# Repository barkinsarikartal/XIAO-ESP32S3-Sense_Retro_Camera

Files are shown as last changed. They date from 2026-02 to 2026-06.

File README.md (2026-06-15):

# XIAO ESP32-S3 Sense Retro Camera

A compact retro-styled digital camera built on the Seeed Studio XIAO ESP32-S3 Sense. Captures high-resolution photos and MJPEG/PCM audio video, with a live viewfinder on a 2.0" TFT display. Features a full encoder-driven menu system with on-device gallery (including video thumbnail previews), camera settings, self-timer countdown, timelapse mode, photo slideshow, and a tabbed wireless file manager. Modular codebase with a multi-task FreeRTOS architecture for robust, concurrent operation.

---

## Demo Video

<div align="center">
  <a href="https://youtu.be/0UTXGptOVkc">
    XIAO ESP32-S3 Retro Camera — Demo Video
  </a>
  <br>
  <strong><a href="https://youtu.be/0UTXGptOVkc">Watch the full demo on YouTube</a></strong>
</div>

---

## Features

- **High-Resolution Photo Capture** — HD JPEG images (1280×720) saved to SD card
- **Video Recording with Audio** — MJPEG video at 480×320, 10 FPS, with 16 kHz mono PCM audio via the built-in PDM microphone, saved as `.avi`
- **Live Viewfinder** — Real-time 320×240 RGB565 camera preview on the TFT display
- **Main Menu** — Encoder-driven main menu with Gallery, WiFi Transfer, Camera Settings, Timelapse, Slideshow, and Exit options
- **Camera Settings** — On-device configuration of 15 parameters (brightness, contrast, saturation, AE level, white balance, special effects, mirror, flip, JPEG quality, timelapse interval, recording duration limit, flashlight toggle, file counter reset, self-timer, slideshow interval) with NVS persistence
- **Self-Timer** — Configurable countdown (3 / 5 / 10 s) before photo capture; large digit on TFT; LED blinks slowly then rapidly in the last second; cancel anytime with the shutter button
- **Timelapse Mode** — Periodic HD photo capture at configurable intervals (5s–10min); TFT shows countdown, photo count, elapsed time; pause/resume/stop via encoder
- **Slideshow Mode** — Auto-advance full-screen photo slideshow from the main menu; configurable interval (3 / 5 / 10 s); pause/resume (encoder click), exit (encoder long press), emergency exit (shutter)
- **Recording Duration Limit** — Configurable auto-stop for video recording (30s–15min or unlimited)
- **LED Flashlight & Recording Indicator** — General-purpose LED flashlight that also acts as a 1 Hz blinking recording indicator or continuous video light; also blinks as self-timer cue
- **FPS Counter & SD Status** — Live overlay showing frame rate and SD card health
- **WiFi File Server** — AP mode with a tabbed HTML file manager (Photos / Videos tabs with file count badges, sorted newest-first); download with browser progress bar, preview, delete individual files, **bulk-select and delete multiple files**, or **delete all** photos/videos in one tap; video thumbnail support; **QR code pairing screen** on the TFT displays credentials and a scannable WIFI: QR code for instant phone connection
- **On-Device Gallery** — Browse photos and videos in a **4×3 thumbnail grid** (12 items per page); drill into a full-screen detail view with encoder click; video thumbnails show a play icon overlay; page indicator shows current position
- **Silent Video Playback** — Plays AVI recordings on the TFT by parsing MOVI JPEG chunks; frame timing derived from the AVI header's `microSecPerFrame` for accurate real-time speed; pause/resume/stop via encoder
- **File Deletion** — Delete photos and videos directly from the device with a confirmation dialog
- **Reliable AVI Encoding** — Accurate `idx1` index table built from actual chunk write order; `microSecPerFrame` derived from declared target FPS; `endAVI()` safely handles SD removal mid-recording
- **A/V Synchronisation** — I2S DMA geometry tuned to drain exactly one video frame's worth of audio per read (`AUDIO_BYTES_PER_FRAME = 3200` bytes, 10×320-byte DMA slots); fixes cumulative drift
- **Atomic Multi-Core Synchronisation** — `std::atomic<int>` for all inter-core display-buffer state, preventing SMP data races
- **PSRAM Efficiency** — Separate `DISP_BUF_SIZE` (160 KB) and `REC_BUF_SIZE` (80 KB) buffer pools save 240 KB PSRAM; AVI metadata arrays allocated once at boot and `memset` per session

---

## Hardware

| Component | Part |
|---|---|
| Microcontroller | Seeed Studio XIAO ESP32-S3 Sense (OV2640 + SD card expansion) |
| Display | 2.0" TFT LCD — ST7789VW, 240×320, SPI |
| Rotary Encoder | EC11 with push button (CLK: GPIO 6, DT: GPIO 43, SW: GPIO 44) |
| Shutter button | 1× tactile button (GPIO 5 to GND) |
| LED Flashlights | 2× 5mm white LEDs with 100Ω resistor (GPIO 4) |
| Storage | MicroSD card, FAT32 formatted |
| Power | 3.7 V Li-ion battery or USB-C |

---

## Pin Configuration

<div align="center">
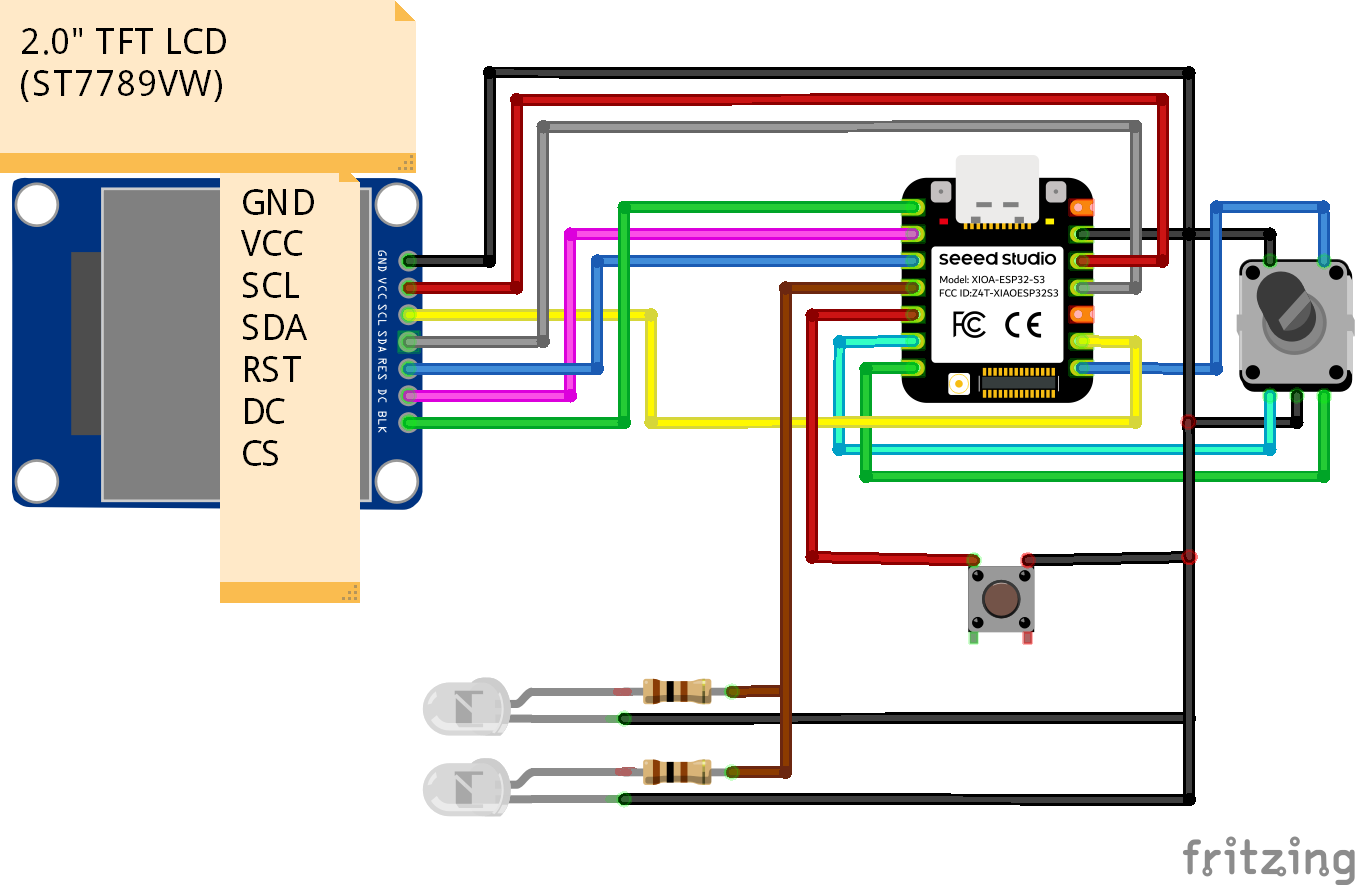
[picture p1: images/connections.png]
Connection Diagram
  
  <br><br>
  <table>
    <tr>
      <td valign="top" align="center">
        <h3>TFT Display (ST7789VW)</h3>
        <table>
          <tr><th>TFT Pin</th><th>GPIO</th></tr>
          <tr><td>GND</td><td>GND</td></tr>
          <tr><td>VCC</td><td>3.3 V</td></tr>
          <tr><td>SCL (SCK)</td><td>GPIO 7</td></tr>
          <tr><td>SDA (MOSI)</td><td>GPIO 9</td></tr>
          <tr><td>RESET</td><td>GPIO 3</td></tr>
          <tr><td>DC</td><td>GPIO 2</td></tr>
          <tr><td>CS</td><td>GPIO 1</td></tr>
        </table>
      </td>
      <td width="20"></td>
      <td valign="top" align="center">
        <h3>Buttons & Control</h3>
        <table>
          <tr><th>Function</th><th>GPIO</th></tr>
          <tr><td>Encoder CLK</td><td>GPIO 6 (INPUT_PULLUP)</td></tr>
          <tr><td>Encoder DT</td><td>GPIO 43 (INPUT_PULLUP)</td></tr>
          <tr><td>Encoder SW (Button)</td><td>GPIO 44 (INPUT_PULLUP)</td></tr>
          <tr><td>Shutter</td><td>GPIO 5 (INPUT_PULLUP to GND)</td></tr>
          <tr><td>LED Flashlights with 100Ω Resistor</td><td>GPIO 4 (OUTPUT)</td></tr>
          <tr><td>SD Card CS</td><td>GPIO 21</td></tr>
          <tr><td>Mic CLK (PDM)</td><td>GPIO 42</td></tr>
          <tr><td>Mic DATA (PDM)</td><td>GPIO 41</td></tr>
          <tr><td colspan="2"><em>TFT and SD share SPI2_HOST (MISO: GPIO 8)</em></td></tr>
        </table>
      </td>
    </tr>
  </table>
</div>

---

## 3D Printable Parts

The enclosure is fully 3D-printable. STL files for the camera case are included in the [`models/`](models/) directory; the XIAO case and accessory parts are sourced from the community.

### Camera Case (included in repo)

| File | Description |
|---|---|
| [`box_final.stl`](models/box_final.stl) | Main body / enclosure box |
| [`cam_final.stl`](models/cam_final.stl) | Front camera mount |
| [`2inc_tft_final.stl`](models/2inc_tft_final.stl) | Rear TFT display frame (2.0" ST7789) |

**Assembly hardware:** 8× M3×5.75 brass heat-set inserts + 8× M3×5 screws.

<div align="center">
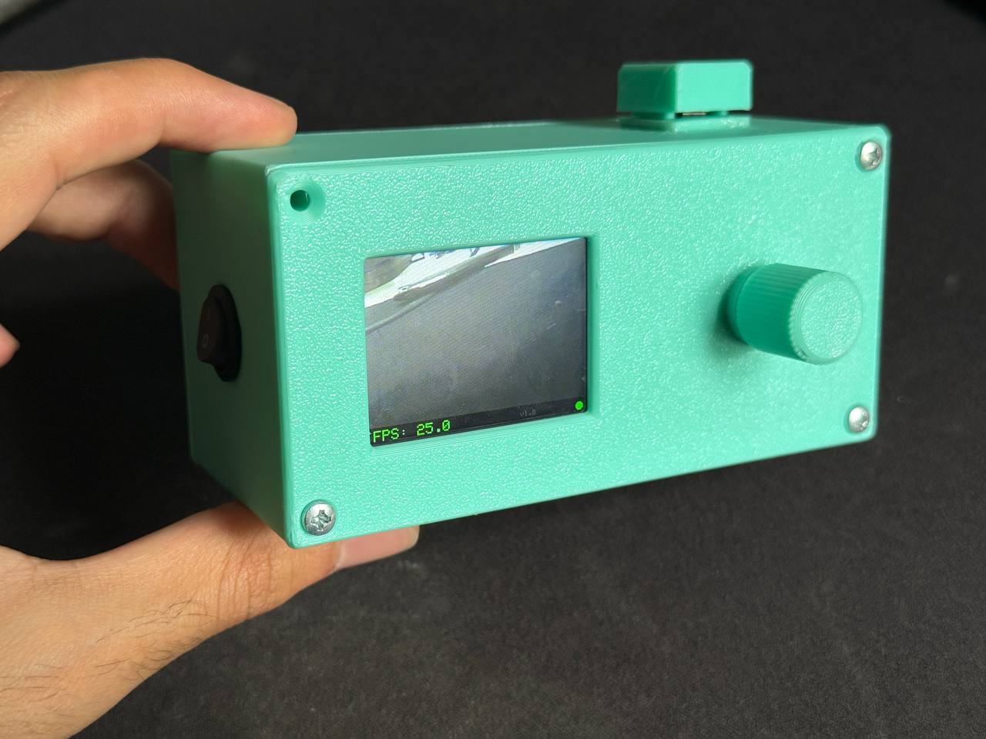
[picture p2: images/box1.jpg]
Camera case – view 1
  
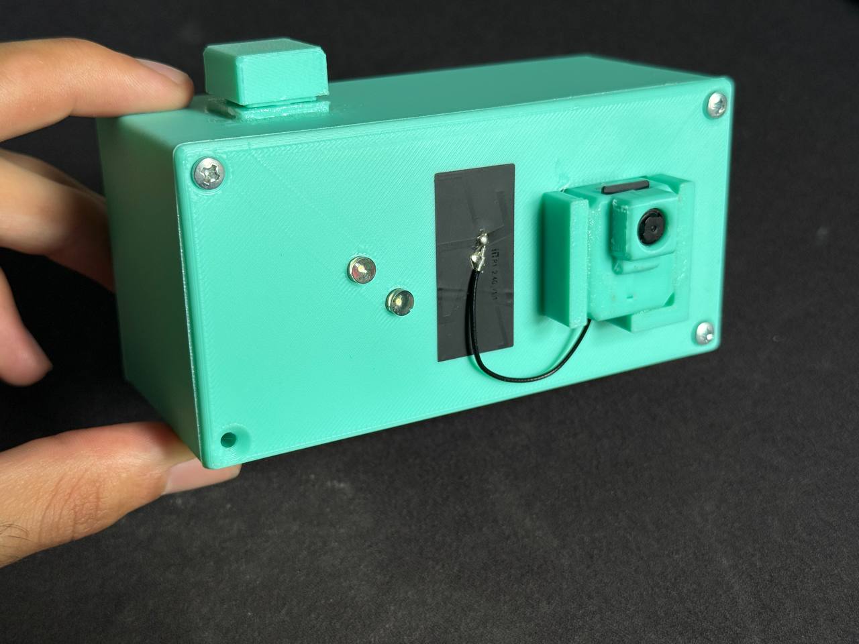
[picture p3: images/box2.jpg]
Camera case – view 2
  
</div>

### XIAO ESP32-S3 Sense Case

| File | Source |
|---|---|
| [`xiao_case_right.stl`](models/xiao_case_right.stl) | [XIAO Sense Case – Printables #681623](https://www.printables.com/model/681623-xiao-sense-case-seeed-studio-xiao-esp32s3-sense-ca) |
| [`xiao_case_left.stl`](models/xiao_case_left.stl) | Same source (left half) |

### External Parts (MakerWorld)

| Part | Link |
|---|---|
| Shutter Button Assembly (18 mm cap for 6 mm push button) | [MakerWorld #628744](https://makerworld.com/tr/models/628744-18mm-button-assembly-for-6mm-push-buttons) |
| EC11 Encoder Knob (split shaft) | [MakerWorld #2430821](https://makerworld.com/tr/models/2430821-ec11-encoder-knob-split-shaft) |

---

## Installation & Setup

### PlatformIO (Recommended)

1. Install **Visual Studio Code** with the PlatformIO extension
2. Clone / open this folder in VS Code
3. PlatformIO auto-detects `seeed_xiao_esp32s3` from `platformio.ini`
4. **Build:** `PlatformIO: Build`
5. **Upload:** Connect XIAO via USB-C → `PlatformIO: Upload`
6. **Monitor:** Serial monitor at **115200 baud**

### Arduino IDE

1. Board Manager URL: `https://raw.githubusercontent.com/espressif/arduino-esp32/gh-pages/package_esp32_index.json`
2. Install **esp32 by Espressif Systems** (v3.x+)
3. Board: **XIAO_ESP32S3** | PSRAM: **OPI PSRAM**
4. Install **LovyanGFX** via Library Manager
5. Open `src/main.cpp` (or the whole project folder), upload

---

## Usage

### Taking a Photo
- **Short press** (< 1 s) the shutter button
- Camera switches to HD mode, captures, saves → `/pic_N.jpg`
- Screen shows "HOLD ON…" then "PIC SAVED #N"

### Recording Video
- **Long press** (> 1 s) the shutter button to start
- Records MJPEG + PCM audio → `/vid_N.avi`
- Screen shows blinking red indicator + elapsed time HH:MM:SS, and physical LED blinks at 1 Hz (or acts as continuous video light if flashlight is enabled)
- **Press again** to stop (minimum 2 s of recording)

### WiFi File Manager
- Select **WiFi Transfer** from the main menu (requires SD card)
- The TFT shows a **split-screen pairing display**: text credentials on the left (SSID, password, IP) and a **scannable QR code** on the right
  - **Phone users:** point your camera at the QR code — iOS and Android recognise the `WIFI:` URI format and offer a one-tap "Connect to WiFi" prompt, no password typing needed
  - **PC/laptop users:** connect manually to `Retro_Cam` (password: `barkinsarikartal`)
- Navigate to `http://192.168.4.1` — tabbed interface: **Photos** and **Videos** tabs, each sorted **newest-first** with file count badges
- Both photos and videos display thumbnail previews; video thumbnails are extracted from frame ~1.2 s into the clip
- Downloads include a `Content-Length` header so the browser shows a progress bar with percentage
- **Bulk delete:** tap **☑ Select** to enter selection mode, check individual files, then **Delete Selected (N)** — a single confirmation before deleting
- **Delete all:** tap **⚠ Delete All** to remove every file in the current tab (Photos or Videos) with one confirmation
- Press the encoder click/long to exit WiFi mode and resume camera

### SD Card Status
- **Green dot** (bottom-right) = SD ready
- **Red dot** = card missing, full, or error
- Recording auto-stops if card is removed or full

### Menu System
- **Encoder click** from Idle → Main Menu
- **Turn** (CW / CCW) to highlight an option, **click** to select
- **Long press** at any level = go back (universal)
- Menu items: **Gallery**, **WiFi Transfer**, **Settings**, **Timelapse**, **Slideshow**, **Exit**

### Gallery (Photos & Videos)
- Select "Gallery" from the main menu → Gallery type selector (Photos / Videos)
- **CW / CCW** to switch between types, **click** to enter
- **Grid View (4×3 thumbnails):**
  - CW/CCW to move cursor between cells; wraps to next/previous page automatically
  - Page indicator in header shows "Photos 2/5" or "Videos 1/3"
  - **Click** to drill down to the full-screen detail view
  - **Long press** to go back to gallery type selector
- **Photo Detail View:** shows full-size photo (1280×720 scaled), filename, file size; CW/CCW to browse photos; click → delete dialog; long press → back to grid
- **Video Detail View:** shows thumbnail + play icon + filename + file size; CW/CCW to browse; click → play video; long press → back to grid
- **During Video Playback:** plays at accurate real-time speed (frame timing from AVI header); click to pause/resume, long press to stop → delete dialog
- **File Deletion:** Confirmation dialog with Cancel/Delete before removing from SD; after deletion returns to grid view
- **Shutter button** exits any menu/gallery state immediately (emergency exit)

### Taking a Photo — Self-Timer
- Open **Settings → Self Timer** and choose 3s, 5s, or 10s (default: Off)
- Press the shutter button — the screen shows a large digit countdown with LED blink cues
- LED blinks slowly for the first N-1 seconds, then rapidly in the final second (classic camera cue)
- **Press shutter again at any time** to cancel the countdown
- At 0 the photo is taken automatically via the normal HD capture path

### Camera Settings
- Select "Settings" from the main menu
- **CW / CCW** to browse the 15 parameters (scrollable list)
- **Click** to enter edit mode (highlighted row turns yellow)
- **CW / CCW** to adjust the value within its valid range
- **Click** to confirm and save to NVS
- **Long press** in edit mode cancels the change
- **Long press** in browse mode returns to the main menu
- Available settings: Brightness, Contrast, Saturation, AE Level, White Balance, Effect, H Mirror, V Flip, JPEG Quality, TL Interval, Rec Limit, Flashlight, Reset Counter, Self Timer, Slide Interval
- **Reset Counter:** Resets the photo and video file counters in NVS to 0. Uses a two-step confirm (No / YES) to prevent accidental resets. After confirming, a warning screen reminds you to back up your files via WiFi and delete them from the SD card before capturing new ones (the camera will skip over existing filenames automatically, but gallery display will be out of order until the SD is clean)

### Slideshow Mode
- Select **Slideshow** from the main menu (requires SD card with at least one photo)
- Photos cycle full-screen automatically at the configured interval (Settings → Slide Interval: 3s / 5s / 10s)
- Header bar shows current position (e.g. "Slideshow 2 / 8") and filename
- **Encoder click** — pause / resume (two-bar indicator appears top-left when paused)
- **Encoder long press** — exit to main menu
- **Shutter short press** — emergency exit to idle viewfinder
- **Shutter long press** — exit slideshow and immediately start video recording

### Timelapse Mode
- Select "Timelapse" from the main menu (requires SD card)
- Camera switches to HD mode; captures photos at the configured interval
- TFT shows countdown to next capture, photo count, and elapsed time
- **Click** the encoder to pause/resume
- **Long press** the encoder or **press shutter** to stop → returns to idle

---
### Source Code Structure

| File | Responsibility |
|---|---|
| `shared.h` | Common includes, defines, structs, enums, LGFX class, extern declarations, prototypes |
| `main.cpp` | setup/loop, FreeRTOS tasks (capture, display, recorder, input, SD monitor), ISRs, camera/mic init |
| `avi_writer.cpp` | AVI file creation: startAVI, writeAVIFrameFromBuf, writeAVIAudioChunk, endAVI |
| `wifi_server.cpp` | WiFi AP + async web server with tabbed HTML file manager |
| `gallery.cpp` | On-device gallery: photo/video browsing, AVI frame extraction, video playback |
| `settings.cpp` | Camera settings: NVS load/save, applySettings, settings & main menu UI |
| `qr_render.cpp` | WiFi pairing screen: QR code generation (WIFI: URI) + split-screen TFT layout |

## Technical Details

### Recording Configuration

| Setting | Live Preview | Photo | Video |
|---|---|---|---|
| Format | RGB565 | JPEG | JPEG |
| Resolution | QVGA 320×240 | HD 1280×720 | HVGA 480×320 |
| Target FPS | — | — | 10 |
| JPEG Quality | — | 12 | 12 |

### A/V Synchronisation

Audio timing is pinned exactly to video frame rate:

```
AUDIO_SAMPLE_RATE       = 16 000 Hz
TARGET_FPS              = 10
AUDIO_SAMPLES_PER_FRAME = 1 600
AUDIO_BYTES_PER_FRAME   = 3 200

I2S DMA: dma_frame_num=160 → 320 bytes/slot
         3200 / 320 = 10 slots = exactly 1 video frame interval
```

Every video frame always receives one audio chunk (zero-padded if the DMA hasn't filled completely). `microSecPerFrame` in the AVI header is written from `TARGET_FPS`, not a variable post-recording average.

### File Storage

| File | Path pattern | Counter storage |
|---|---|---|
| Photo | `/hd_pic_N.jpg` | NVS (`cnt` namespace) |
| Video | `/vid_N.avi` | NVS (`cnt` namespace) |

### FreeRTOS Task Architecture

| Task | Core | Priority | Stack | Responsibility |
|---|---|---|---|---|
| taskSDMonitor | 0 | 1 | 4 KB | SD health, free space, removal detection (skips SPI polling during recording) |
| taskInput | 0 | 2 | 4 KB | Button/encoder debounce, menu state machine |
| taskRecorder | 0 | 4 | 8 KB | SD write, I2S audio read, AVI chunk output |
| taskDisplay | 1 | 3 | 16 KB | TFT frame rendering, menus, gallery UI, video playback |
| taskCapture | 1 | 6 | 8 KB | Camera capture, state transitions, display/recorder buffer copy |

**Synchronisation primitives:**
- `spiMutex` — serialises all SPI bus access (TFT + SD share `SPI2_HOST`)
- `std::atomic<int>` — dispWriteSlot, dispReadSlot, dispRendering (inter-core display state)
- `recFrameQueue` — decouples capture from SD write (3-slot PSRAM pool)
- `recPoolFree` semaphore — backpressure: slows capture when SD is slow

---

## Assembly & Power Notes

Components are soldered on perfboard, powered by a 3.7 V 18650 Li-ion cell.

> **Important:** When powered via the battery connector, the XIAO's 5 V pin is disabled. Connect the **TFT VCC and LED to 3.3 V** to ensure correct operation on battery power.

---

## Troubleshooting

| Symptom | Check |
|---|---|
| "Cam init error" in serial | USB power ≥ 500 mA; OV2640 ribbon cable seated |
| Inverted colours on TFT | Toggle `pcfg.invert` in `initCamera()` |
| SD not detected | FAT32 format; < 32 GB recommended; check GPIO 21 CS |
| AVI won't play | Use VLC; some players don't support MJPEG in AVI |
| Green / overexposed viewfinder after long use | A camera watchdog reinits the OV2640 every 30 s in IDLE mode to prevent AEC/AGC gain drift; if it occurs before the watchdog fires, press the encoder to enter and exit the menu (this triggers a camera reinit) |

---

## Performance

| Metric | Typical value |
|---|---|
| Viewfinder FPS | 15–25 FPS |
| Photo save time | 3–5 seconds |
| Video recording FPS | 9–10 FPS |
| RAM usage | ~18.0% of 320 KB |
| Flash usage | ~38.5% of 3.3 MB |

---

## License

MIT License — see `LICENSE` for details.

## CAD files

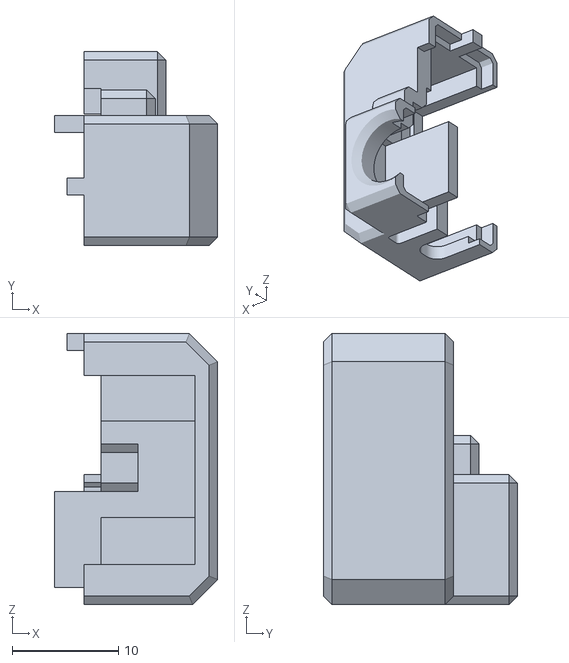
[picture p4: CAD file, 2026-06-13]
models/xiao_case_left.stl
15.3 x 18.2 x 25.5

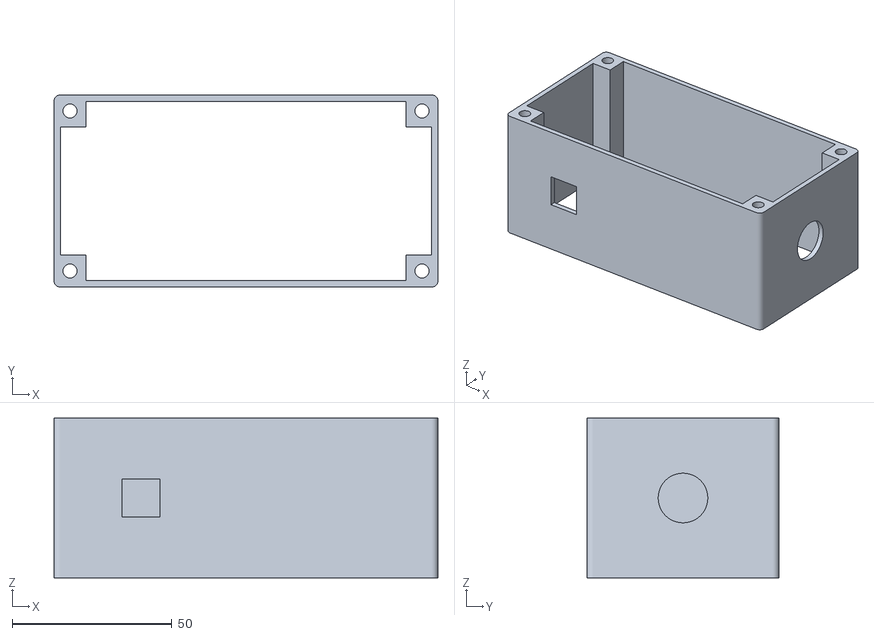
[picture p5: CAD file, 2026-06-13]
models/box_final.stl
120.0 x 60.0 x 50.0

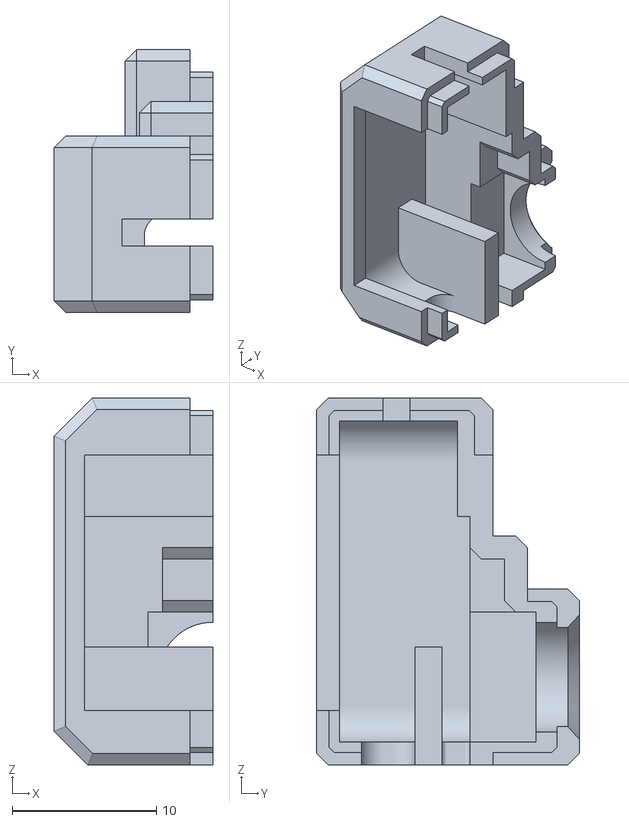
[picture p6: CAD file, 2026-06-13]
models/xiao_case_right.stl
11.0 x 18.2 x 25.5

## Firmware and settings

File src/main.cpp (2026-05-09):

#include "shared.h"

// ================= NVS NAMESPACES =================
// "cnt" — file counters (pictureNumber, videoNumber)
// "cam" — camera sensor settings (CameraSettings struct)

// ================= ENCODER STATE TABLE =================
// Quadrature state table — DRAM_ATTR ensures ISR-safe access during flash operations.
// Index = (prevState << 2) | currState, where state = (CLK << 1) | DT.
// +1 = CW step, -1 = CCW step, 0 = invalid/bounce (ignored).
static const DRAM_ATTR int8_t ENC_TABLE[16] = {
   0, -1,  1,  0,
   1,  0,  0, -1,
  -1,  0,  0,  1,
   0,  1, -1,  0
};

// ================= GLOBAL VARIABLE DEFINITIONS =================
// All globals declared as extern in shared.h are defined here (except
// AVI writer globals in avi_writer.cpp and webServer in wifi_server.cpp).

LGFX tft;
SemaphoreHandle_t spiMutex;
volatile AppState appState = STATE_IDLE;
EventGroupHandle_t appEvents;
QueueHandle_t inputEventQueue = NULL;
SDStatus globalSDState = {false, false, "NO CARD"};
CameraSettings camSettings = { 1, 0, 2, 0, 0, 0, 1, 0, 12, 10, 0, 0, 0, 5 };
camera_config_t config;
int pictureNumber = 0;
int videoNumber = 0;
unsigned long recordingStartTime = 0;
File videoFile;
TaskHandle_t taskDisplayHandle = NULL;

// Display double buffer
uint8_t *dispBuf[2] = {nullptr, nullptr};
volatile size_t dispLen[2] = {0, 0};
std::atomic<int> dispWriteSlot{0};
std::atomic<int> dispReadSlot{-1};
std::atomic<int> dispRendering{-1};

// Recorder pool
uint8_t *recPool[REC_POOL_SIZE] = {nullptr, nullptr, nullptr};
QueueHandle_t recFrameQueue = NULL;
SemaphoreHandle_t recPoolFree = NULL;
int recPoolWriteIdx = 0;

// Audio
int16_t *audioRecBuf = nullptr;
i2s_chan_handle_t i2s_rx_handle = NULL;

// Gallery state
char **galleryFiles = nullptr;
int galleryFileCount = 0;
int galleryIndex = 0;
int galleryTypeSelection = 0;
int deleteSelection = 0;
volatile bool galleryNeedsRedraw = false;

// Menu state
int menuMainSelection = 0;
int settingsIndex = 0;
bool settingsEditing = false;
int resetCounterConfirm = 0;

// Encoder ISR state — DRAM_ATTR keeps these in internal SRAM so ISRs
// can access them safely even during flash cache misses (e.g. SD writes).
DRAM_ATTR volatile uint8_t encPrevState = 3;   // both HIGH at boot (INPUT_PULLUP default)
DRAM_ATTR volatile int8_t  encAccum     = 0;   // direction accumulator between detents
DRAM_ATTR volatile uint32_t encSwPressMs = 0;  // timestamp of SW button press edge

// Debug counters: ISR increments, taskInput reads and prints the delta.
// Safe because uint32 reads/writes are atomic on Xtensa; no mutex needed.
#if DEBUG_INPUT
volatile uint32_t dbgEncCw    = 0;
volatile uint32_t dbgEncCcw   = 0;
volatile uint32_t dbgEncClick = 0;
volatile uint32_t dbgEncLong  = 0;
#endif

// ================= TASK PROTOTYPES (file-local) =================
static void taskSDMonitor(void *pvParameters);
static void taskCapture(void *pvParameters);
static void taskDisplay(void *pvParameters);
static void taskRecorder(void *pvParameters);
static void taskInput(void *pvParameters);
static void savePhotoHighRes();
static void drawStatusBar(float fps);
static void encoderISR();
static void encSwISR();
static void runTimelapse();
static void runSelfTimerCountdown();
static void runBootAnimation();

// ================= SETUP =================
void setup() {
  Serial.begin(115200);
#if DEBUG_BOOT_DELAY
  delay(8000);  // Long delay for Serial Monitor attachment during debugging
#else
  delay(1000);
#endif

  WiFi.mode(WIFI_OFF);
  esp_bt_controller_disable();

  // Boot button (GPIO 0) no longer used — mirror and WiFi are in encoder menu.
  pinMode(SHUTTER_BTN_PIN_2, INPUT_PULLUP);

  // LED flashlight output (GPIO4). Always starts OFF — the LED only activates
  // during photo capture or video recording, never in idle or menus.
  pinMode(LED_FLASHLIGHT_PIN, OUTPUT);
  digitalWrite(LED_FLASHLIGHT_PIN, LOW);

  pinMode(ENC_CLK, INPUT_PULLUP);
  pinMode(ENC_DT,  INPUT_PULLUP);
  pinMode(ENC_SW,  INPUT_PULLUP);

  spiMutex = xSemaphoreCreateMutex();
  appEvents = xEventGroupCreate();
  inputEventQueue = xQueueCreate(16, sizeof(InputEvent));
  recFrameQueue = xQueueCreate(REC_POOL_SIZE, sizeof(RecFrame));
  recPoolFree = xSemaphoreCreateCounting(REC_POOL_SIZE, REC_POOL_SIZE);

  SPI.begin(TFT_SCK, TFT_MISO, TFT_MOSI, SD_CS_PIN);
  delay(100);

  tft.init();
  tft.setRotation(1);
  tft.fillScreen(TFT_BLACK);

  // Boot animation — retro first impression before hardware init
  runBootAnimation();

  // Load file counters from NVS
  {
    Preferences p;
    p.begin("cnt", true);  // read-only
    pictureNumber = p.getInt("pic", 0);
    videoNumber   = p.getInt("vid", 0);
    p.end();
  }

  // Load camera settings from NVS
  loadCameraSettings();

  // Build EXIF metadata block (cached in PSRAM for all photo saves)
  buildExifBlock();

  Serial.printf("Initial image no: %d, video no: %d\n", pictureNumber, videoNumber);

  // CAMERA CONFIG
  config.ledc_channel = LEDC_CHANNEL_0;
  config.ledc_timer   = LEDC_TIMER_0;
  config.pin_d0       = Y2_GPIO_NUM;
  config.pin_d1       = Y3_GPIO_NUM;
  config.pin_d2       = Y4_GPIO_NUM;
  config.pin_d3       = Y5_GPIO_NUM;
  config.pin_d4       = Y6_GPIO_NUM;
  config.pin_d5       = Y7_GPIO_NUM;
  config.pin_d6       = Y8_GPIO_NUM;
  config.pin_d7       = Y9_GPIO_NUM;
  config.pin_xclk     = XCLK_GPIO_NUM;
  config.pin_pclk     = PCLK_GPIO_NUM;
  config.pin_vsync    = VSYNC_GPIO_NUM;
  config.pin_href     = HREF_GPIO_NUM;
  config.pin_sccb_sda = SIOD_GPIO_NUM;
  config.pin_sccb_scl = SIOC_GPIO_NUM;
  config.pin_pwdn     = PWDN_GPIO_NUM;
  config.pin_reset    = RESET_GPIO_NUM;
  config.xclk_freq_hz = 20000000;

  initCamera(IDLE_MODE, IDLE_RESOLUTION, IDLE_JPEG_QUALITY);

  allocateBuffers();

  delay(2000);

  // Task: SD Card Monitor (Core 0, Priority 1)
  xTaskCreatePinnedToCore(taskSDMonitor, "SD_Mon", 4096, NULL, 1, NULL, 0);

  // Task: Button/Input Handler (Core 0, Priority 2)
  xTaskCreatePinnedToCore(taskInput, "Input", 4096, NULL, 2, NULL, 0);

  // Task: AVI Recorder / SD Writer (Core 0, Priority 4)
  xTaskCreatePinnedToCore(taskRecorder, "Recorder", 8192, NULL, 4, NULL, 0);

  // Task: TFT Display (Core 1, Priority 3)
  xTaskCreatePinnedToCore(taskDisplay, "Display", 16384, NULL, 3, &taskDisplayHandle, 1);

  // Task: Camera Capture (Core 1, Priority 6 - highest)
  xTaskCreatePinnedToCore(taskCapture, "Capture", 8192, NULL, 6, NULL, 1);

  // Attach encoder interrupts AFTER tasks are created so the queue exists.
  attachInterrupt(digitalPinToInterrupt(ENC_CLK), encoderISR, CHANGE);
  attachInterrupt(digitalPinToInterrupt(ENC_DT),  encoderISR, CHANGE);
  attachInterrupt(digitalPinToInterrupt(ENC_SW),  encSwISR,  CHANGE);
  Serial.println("Encoder ISRs attached (CLK+DT+SW).");

  Serial.println("Cam is ready. Tasks launched.");
}

// ================= LOOP =================
void loop() {
  vTaskDelete(NULL);
}

// ================= BUFFER ALLOCATION =================
void allocateBuffers() {
  for (int i = 0; i < 2; i++) {
    dispBuf[i] = (uint8_t*)ps_malloc(DISP_BUF_SIZE);
    if (!dispBuf[i]) Serial.printf("[ERR] dispBuf[%d] alloc failed!\n", i);
  }
  for (int i = 0; i < REC_POOL_SIZE; i++) {
    recPool[i] = (uint8_t*)ps_malloc(REC_BUF_SIZE);
    if (!recPool[i]) Serial.printf("[ERR] recPool[%d] alloc failed!\n", i);
  }
  audioRecBuf = (int16_t*)ps_malloc(AUDIO_REC_BUF_SIZE);
  if (!audioRecBuf) Serial.println("[ERR] audioRecBuf alloc failed!");

  // AVI metadata arrays: allocated ONCE at boot to prevent PSRAM heap fragmentation.
  // startAVI() only clears them with memset; endAVI() never frees them.
  avi_frame_sizes = (uint32_t*)ps_malloc(MAX_AVI_FRAMES * sizeof(uint32_t));
  if (!avi_frame_sizes) Serial.println("[ERR] avi_frame_sizes alloc failed!");
  avi_audio_sizes = (uint32_t*)ps_malloc(MAX_AVI_FRAMES * sizeof(uint32_t));
  if (!avi_audio_sizes) Serial.println("[ERR] avi_audio_sizes alloc failed!");
  avi_chunk_order = (uint8_t*)ps_malloc(MAX_AVI_CHUNKS);
  if (!avi_chunk_order) Serial.println("[ERR] avi_chunk_order alloc failed!");

  Serial.printf("[MEM] Free PSRAM after boot alloc: %u bytes\n",
                heap_caps_get_free_size(MALLOC_CAP_SPIRAM));
}

// Centred transient message. Pausing taskDisplay during the hold is essential
// in IDLE — otherwise the next camera frame pushes over the text within ~40 ms
// and the user only sees a one-frame flash of e.g. "NO SD CARD!".
void showTFTMessage(const char *msg, uint16_t color, int durationMs) {
  AppState saved = appState;
  bool pauseDisplay = (durationMs > 0 && saved == STATE_IDLE);
  if (pauseDisplay) appState = STATE_PHOTO;

  if (xSemaphoreTake(spiMutex, portMAX_DELAY)) {
    tft.fillRect(0, 80, 320, 60, TFT_BLACK);
    tft.setTextDatum(middle_center);
    tft.setTextSize(2);
    tft.setTextColor(color);
    tft.drawString(msg, tft.width() / 2, 110);
    tft.setTextDatum(top_left);
    xSemaphoreGive(spiMutex);
  }
  if (durationMs > 0) vTaskDelay(pdMS_TO_TICKS(durationMs));

  if (pauseDisplay) appState = saved;
}

// ================= HELPER: EMERGENCY EXIT =================
// Exits any menu/gallery state back to IDLE. Reverts uncommitted settings edits,
// frees gallery memory, reinits camera and clears the screen.
void emergencyExitToIdle() {
  Serial.println("[MENU] Emergency exit -> IDLE");
  if (settingsEditing) {
    loadCameraSettings();
    settingsEditing = false;
  }
  freeGalleryFiles();
  initCamera(IDLE_MODE, IDLE_RESOLUTION, IDLE_JPEG_QUALITY);
  if (xSemaphoreTake(spiMutex, portMAX_DELAY)) {
    tft.fillScreen(TFT_BLACK);
    xSemaphoreGive(spiMutex);
  }
  appState = STATE_IDLE;
}

// ================= TASK: SD MONITOR (Core 0, Priority 1) =================
static void taskSDMonitor(void *pvParameters) {
  while (true) {
    // WiFi mode: lightweight SD presence check only.
    // Skip remount attempts (SD.end/begin) to avoid colliding with active downloads.
    // Update globalSDState so web routes return correct errors if SD removed.
    // Update TFT status so user can see SD state without browser.
    if (appState == STATE_WIFI_MODE) {
      if (xSemaphoreTake(spiMutex, pdMS_TO_TICKS(500)) == pdTRUE) {
        bool wasMounted = globalSDState.isMounted;
        if (SD.cardType() == CARD_NONE || SD.totalBytes() == 0) {
          globalSDState.isMounted = false;
          globalSDState.isFull = false;
          globalSDState.errorMsg = "SD REMOVED";
        } else {
          globalSDState.isMounted = true;
          uint64_t freeBytes = SD.totalBytes() - SD.usedBytes();
          globalSDState.isFull = (freeBytes < 10 * 1024 * 1024);
          globalSDState.errorMsg = globalSDState.isFull ? "SD FULL" : "READY";
        }
        xSemaphoreGive(spiMutex);

        // SD state changed — update TFT bottom bar
        if (wasMounted != globalSDState.isMounted) {
          if (xSemaphoreTake(spiMutex, pdMS_TO_TICKS(200))) {
            tft.fillRect(0, 210, 320, 30, TFT_BLACK);
            tft.setTextDatum(middle_center);
            tft.setTextSize(1);
            if (!globalSDState.isMounted) {
              tft.setTextColor(TFT_RED);
              tft.drawString("! SD CARD REMOVED !", tft.width() / 2, 220);
              Serial.println("[WIFI] SD card removed during WiFi mode.");
            } else {
              tft.setTextColor(0x7BEF);
              tft.drawString("Press to exit", tft.width() / 2, 220);
              Serial.println("[WIFI] SD card re-inserted during WiFi mode.");
            }
            tft.setTextDatum(top_left);
            xSemaphoreGive(spiMutex);
          }
        }
      }
      vTaskDelay(pdMS_TO_TICKS(3000));
      continue;
    }

    // During recording: skip SD polling entirely. SD removal and space
    // exhaustion are caught by taskRecorder's write error path, which sends
    // EVT_SD_STOP. Polling here would compete for spiMutex with the recorder
    // on every cycle, reducing effective write throughput.
    if (appState == STATE_RECORDING || appState == STATE_STOPPING) {
      vTaskDelay(pdMS_TO_TICKS(2000));
      continue;
    }

    if (xSemaphoreTake(spiMutex, pdMS_TO_TICKS(1000)) == pdTRUE) {

      bool currentMount = false;
      bool currentFull = false;
      String msg = "";

      if (SD.cardType() == CARD_NONE || SD.totalBytes() == 0) {
        SD.end();
        if (!SD.begin(SD_CS_PIN, SPI, 20000000)) {
          currentMount = false;
          msg = "NO SD CARD";
        }
        else {
          currentMount = true;
        }
      }
      else {
        currentMount = true;
      }

      if (currentMount) {
        uint64_t total = SD.totalBytes();
        uint64_t used = SD.usedBytes();
        uint64_t freeSpace = total - used;

        if (freeSpace < 10 * 1024 * 1024) {
          currentFull = true;
          msg = "SD FULL";
        }
        else {
          currentFull = false;
          msg = "READY";
        }
      }

      globalSDState.isMounted = currentMount;
      globalSDState.isFull = currentFull;
      globalSDState.errorMsg = msg;

      xSemaphoreGive(spiMutex);
    }

    vTaskDelay(pdMS_TO_TICKS(2000));
  }
}

// ================= TASK: INPUT HANDLER (Core 0, Priority 2) =================
//
// Queue-based input pipeline.
// All physical inputs are translated into InputEvent and pushed to inputEventQueue.
// Encoder ISRs push CW/CCW/CLICK/LONG directly; shutter button is polled here.
//
// State machine:
//   IDLE -> ENC_CLICK -> MENU_MAIN -> (Gallery | WiFi | Settings | Exit)
//   ENC_LONG = universal "go back one level"
//   SHUTTER short = photo (IDLE), stop recording, or emergency exit from any menu
//   SHUTTER long  = start recording (from IDLE or any menu — auto-exits first)
//
// Boot button disabled in Phase 10 — mirror toggle and WiFi entry handled via encoder menu.
static void taskInput(void *pvParameters) {
  bool lastShutter = HIGH;
  unsigned long shutterPressTime = 0;

  auto sendEvent = [](InputEventType t) {
    InputEvent e = { t };
    xQueueSend(inputEventQueue, &e, 0);
#if DEBUG_INPUT
    static const char* const names[] = {
      "BTN_SHORT", "BTN_LONG",
      "ENC_CW",   "ENC_CCW",  "ENC_CLICK",  "ENC_LONG"
    };
    Serial.printf("[INPUT] %s\n", (t < 6) ? names[t] : "?");
#endif
  };

  while (true) {
    bool shutterNow = digitalRead(SHUTTER_BTN_PIN_2);

    // ── SHUTTER press edge ──
    if (lastShutter == HIGH && shutterNow == LOW) {
      shutterPressTime = millis();
    }

    // ── SHUTTER release edge ──
    if (lastShutter == LOW && shutterNow == HIGH) {
      unsigned long dur = millis() - shutterPressTime;

      if (dur < 1000) {
        // Short press
        if (appState == STATE_IDLE) {
          // Take photo — respect self-timer if configured
          bool canSave = false;
          String errMsg = "";
          if (xSemaphoreTake(spiMutex, pdMS_TO_TICKS(100))) {
            if (!globalSDState.isMounted) errMsg = "NO SD CARD!";
            else if (globalSDState.isFull)  errMsg = "SD FULL!";
            else canSave = true;
            xSemaphoreGive(spiMutex);
          }
          if (canSave) {
            if (camSettings.selftimer_seconds > 0) {
              // Intercept: show countdown, then fire the photo at 0.
              // taskDisplay will call runSelfTimerCountdown() which sends EVT_TAKE_PHOTO.
              appState = STATE_SELFTIMER_COUNTDOWN;
              if (taskDisplayHandle) xTaskNotifyGive(taskDisplayHandle);
            } else {
              xEventGroupSetBits(appEvents, EVT_TAKE_PHOTO);
              sendEvent(INPUT_BTN_SHORT);
            }
          } else {
            showTFTMessage(errMsg.c_str(), TFT_RED, 2000);
          }
        } else if (appState == STATE_SELFTIMER_COUNTDOWN) {
          // Shutter press during countdown cancels it
          appState = STATE_IDLE;
        } else if (appState == STATE_RECORDING && millis() - recordingStartTime > 2000) {
          // Stop recording
          xEventGroupSetBits(appEvents, EVT_STOP_RECORDING);
          sendEvent(INPUT_BTN_SHORT);
        } else if (appState == STATE_TIMELAPSE) {
          // Safe exit: use intermediate state so runTimelapse() handles camera cleanup.
          // Don't call emergencyExitToIdle() — it would race with camera ops in runTimelapse.
          appState = STATE_MENU_MAIN;
        } else if (appState == STATE_SLIDESHOW) {
          // Slideshow: short press = emergency exit to IDLE (reinit camera, same as other menus).
          // runSlideshow() in taskDisplay detects the state change and exits its loop cleanly.
          emergencyExitToIdle();
        } else if (appState == STATE_MENU_MAIN || appState == STATE_SETTINGS ||
                   appState == STATE_GALLERY_TYPE || appState == STATE_GALLERY_PHOTOS ||
                   appState == STATE_GALLERY_VIDEOS || appState == STATE_DELETE_CONFIRM ||
                   appState == STATE_VIDEO_PLAYING ||
                   appState == STATE_GALLERY_PHOTO_VIEW || appState == STATE_GALLERY_VIDEO_VIEW) {
          // Emergency exit from any gallery/menu state -> IDLE
          emergencyExitToIdle();
        }
      }
      // Long press released: timelapse needs explicit cleanup; slideshow handled via isMenu below
      else if (appState == STATE_TIMELAPSE) {
        appState = STATE_MENU_MAIN;
      }
      // Other long presses handled by held detection below
    }

    // ── SHUTTER held long (>1s) -> start recording ──
    // Works from IDLE or any gallery state (exits gallery first, reinits camera)
    {
      AppState cs = appState;
      bool isMenu = (cs == STATE_MENU_MAIN || cs == STATE_SETTINGS ||
                     cs == STATE_GALLERY_TYPE || cs == STATE_GALLERY_PHOTOS ||
                     cs == STATE_GALLERY_VIDEOS || cs == STATE_DELETE_CONFIRM ||
                     cs == STATE_VIDEO_PLAYING || cs == STATE_SLIDESHOW ||
                     cs == STATE_GALLERY_PHOTO_VIEW || cs == STATE_GALLERY_VIDEO_VIEW);
      if (shutterNow == LOW && (cs == STATE_IDLE || isMenu) &&
          (millis() - shutterPressTime > 1000) && shutterPressTime != 0) {
        // Exit menu/gallery first if needed
        if (isMenu) {
          Serial.println("[MENU] Shutter long press -> exit menu, start recording");
          emergencyExitToIdle();
        }

        bool cardReady = false;
        String errorMsg = "";
        if (xSemaphoreTake(spiMutex, pdMS_TO_TICKS(100))) {
          if (!globalSDState.isMounted) errorMsg = "NO SD CARD!";
          else if (globalSDState.isFull)  errorMsg = "SD FULL!";
          else cardReady = true;
          xSemaphoreGive(spiMutex);
        }
        if (cardReady) {
          sendEvent(INPUT_BTN_LONG);
          xEventGroupSetBits(appEvents, EVT_START_RECORDING);
          // wait for state change to avoid re-trigger
          while (appState == STATE_IDLE && digitalRead(SHUTTER_BTN_PIN_2) == LOW) {
            vTaskDelay(pdMS_TO_TICKS(50));
          }
          shutterPressTime = 0;  // re-arm
        } else {
          showTFTMessage(errorMsg.c_str(), TFT_RED, 2000);
          shutterPressTime = 0;
        }
      }
    }

    // ── Process encoder events from ISR queue ──
    // Unified consumer: all encoder-based state transitions handled here.
    // Skipped during video playback, timelapse, and slideshow — those modes consume events directly.
    if (appState != STATE_VIDEO_PLAYING && appState != STATE_TIMELAPSE &&
        appState != STATE_SLIDESHOW && appState != STATE_SELFTIMER_COUNTDOWN) {
      InputEvent ev;
      while (xQueueReceive(inputEventQueue, &ev, 0) == pdTRUE) {
        if (ev.type != INPUT_ENC_CW && ev.type != INPUT_ENC_CCW &&
            ev.type != INPUT_ENC_CLICK && ev.type != INPUT_ENC_LONG) continue;

        switch (appState) {
          case STATE_IDLE:
            if (ev.type == INPUT_ENC_CLICK) {
              // Menu is always accessible regardless of SD state.
              // SD checks happen per-item (Gallery, WiFi) inside STATE_MENU_MAIN.
              menuMainSelection = 0;
              enterMenuMain();
            }
            break;
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

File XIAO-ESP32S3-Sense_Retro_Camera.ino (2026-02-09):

#include <Arduino.h>
#include <LovyanGFX.hpp>
#include <EEPROM.h>
#include "esp_camera.h"
#include "esp_wifi.h"
#include "esp_bt.h"
#include "FS.h"
#include "SD.h"
#include "SPI.h"
#include "img_converters.h" // RGB565 -> JPG
#include "freertos/FreeRTOS.h"
#include "freertos/task.h"
#include "freertos/semphr.h"

//   TFT Pin         ->	   XIAO ESP32-S3
//     VCC           ->	        3V3
//     GND           ->	        GND
//     CS            ->	       GPIO1
//    RESET          ->	       GPIO3
//     A0            ->	       GPIO2
//     SDA           ->	       GPIO9
//     SCK           ->	       GPIO7
//     LED           ->	        3V3

// SHUTTER BUTTON    ->    XIAO ESP32-S3
//      1            ->        GPIO4
//      2            ->        GPIO5

// ================= EXTERNAL PINS =================
#define TFT_CS            1
#define TFT_DC            2
#define TFT_RST           3
#define TFT_SCK           7
#define TFT_MISO          8
#define TFT_MOSI          9

#define BTN_PIN           0  // boot button on XIAO (used for mirroring the image)
#define SD_CS_PIN         21 // SD card CS pin on XIAO ESP32S3 Sense

#define SHUTTER_BTN_PIN_1 4
#define SHUTTER_BTN_PIN_2 5

// ================= CAM PINS (XIAO ESP32-S3 Sense) =================
#define PWDN_GPIO_NUM     -1
#define RESET_GPIO_NUM    -1
#define XCLK_GPIO_NUM     10
#define SIOD_GPIO_NUM     40
#define SIOC_GPIO_NUM     39

#define Y9_GPIO_NUM       48
#define Y8_GPIO_NUM       11
#define Y7_GPIO_NUM       12
#define Y6_GPIO_NUM       14
#define Y5_GPIO_NUM       16
#define Y4_GPIO_NUM       18
#define Y3_GPIO_NUM       17
#define Y2_GPIO_NUM       15
#define VSYNC_GPIO_NUM    38
#define HREF_GPIO_NUM     47
#define PCLK_GPIO_NUM     13

// ================= EEPROM SETTINGS =================
#define EEPROM_SIZE       64
#define EEPROM_ADDR_PIC   0
#define EEPROM_ADDR_VID   4

// ================= CAMERA SETTINGS =================
#define PHOTO_MODE        PIXFORMAT_JPEG
#define PHOTO_RESOLUTION  FRAMESIZE_HD

#define VIDEO_MODE        PIXFORMAT_JPEG
#define VIDEO_RESOLUTION  FRAMESIZE_HVGA

#define IDLE_MODE         PIXFORMAT_RGB565
#define IDLE_RESOLUTION   FRAMESIZE_QQVGA

#define REC_JPEG_QUALITY  12
#define IDLE_JPEG_QUALITY 0

// ================= STRUCTS & GLOBALS =================
struct SDStatus {
  bool isMounted;     // is the card inserted and mounted
  bool isFull;        // is the card full
  String errorMsg;    // error message, if any
};

SDStatus globalSDState = {false, false, "NO CARD"};
int pictureNumber = 0;
int videoNumber = 0;
bool mirror = true;

bool isRecording = false;
volatile bool stopRecordingRequested = false;
unsigned long recordingStartTime = 0;
File videoFile;

SemaphoreHandle_t sdMutex;  // to prevent simultaneous access to the SD card
SemaphoreHandle_t tftMutex; // to prevent typing on the screen simultaneously

camera_config_t config;

// ================= AVI HEADER VARIABLES =================
const int avi_header_size = 224; 
long avi_movi_size = 0;
long avi_index_size = 0;
unsigned long avi_start_time = 0;
int avi_total_frames = 0;
uint32_t *avi_frame_sizes = nullptr;  // allocated in PSRAM (not internal RAM)
int avi_frame_capacity = 0;

// ================= TFT CLASS =================
class LGFX : public lgfx::LGFX_Device {
  lgfx::Panel_ST7735S _panel;
  lgfx::Bus_SPI _bus;

public:
  LGFX() {
    auto bcfg = _bus.config();
    bcfg.spi_host = SPI2_HOST;
    bcfg.spi_mode = 0;
    bcfg.freq_write = 40000000; // 40 MHz
    bcfg.pin_sclk = TFT_SCK;
    bcfg.pin_mosi = TFT_MOSI;
    bcfg.pin_miso = TFT_MISO;
    bcfg.pin_dc   = TFT_DC;
    _bus.config(bcfg);
    _panel.setBus(&_bus);

    auto pcfg = _panel.config();
    pcfg.pin_cs = TFT_CS;
    pcfg.pin_rst = TFT_RST;
    pcfg.panel_width  = 128;
    pcfg.panel_height = 160;
    pcfg.offset_x = 0;
    pcfg.offset_y = 0;
    pcfg.invert = false;
    pcfg.rgb_order = true;
    pcfg.readable = false;

    _panel.config(pcfg);

    setPanel(&_panel);
  }
};

LGFX tft;

// ================= FUNCTION PROTOTYPES =================
void taskSDMonitor(void *pvParameters);
void taskCamera(void *pvParameters);
void savePhotoHighRes();
void initCamera(pixformat_t format, framesize_t size, int jpeg_quality);
void startVideoRecording();
void stopVideoRecording(bool showSavedMsg = true);
void startAVI(File &file, int fps, int width, int height);
bool writeAVIFrame(File &file, camera_fb_t *fb);
void endAVI(File &file, int fps, int width, int height);

// ================= SETUP =================
void setup() {
  Serial.begin(115200);
  delay(1000);

  esp_wifi_stop();
  esp_bt_controller_disable();

  pinMode(BTN_PIN, INPUT_PULLUP);
  pinMode(SHUTTER_BTN_PIN_1, OUTPUT);
  pinMode(SHUTTER_BTN_PIN_2, INPUT_PULLUP);

  digitalWrite(SHUTTER_BTN_PIN_1, LOW);

  sdMutex = xSemaphoreCreateMutex();
  tftMutex = xSemaphoreCreateMutex();

  SPI.begin(TFT_SCK, TFT_MISO, TFT_MOSI, SD_CS_PIN);
  delay(100);

  // TFT
  tft.init();
  tft.setRotation(1);
  tft.fillScreen(TFT_BLACK);

  tft.setTextDatum(middle_center);
  tft.setTextColor(TFT_WHITE);
  tft.setTextSize(2);
  tft.drawString("GETTING READY", tft.width() / 2, 40);
  tft.setTextSize(2);
  tft.drawString("PLEASE WAIT..", tft.width() / 2, 70);
  tft.setTextSize(1);
  tft.drawString("github@barkinsarikartal", tft.width() / 2, 110); // mini ad here :)
  tft.setTextDatum(top_left);

  EEPROM.begin(EEPROM_SIZE);

  pictureNumber = EEPROM.readInt(EEPROM_ADDR_PIC);
  if (pictureNumber < 0 || pictureNumber > 10000) {
    pictureNumber = 0;
    EEPROM.writeInt(EEPROM_ADDR_PIC, pictureNumber);
  }

  videoNumber = EEPROM.readInt(EEPROM_ADDR_VID);
  Serial.printf("Initial video no: %d\n", videoNumber);
  if (videoNumber < 0 || videoNumber > 10000) {
    videoNumber = 0;
    EEPROM.writeInt(EEPROM_ADDR_VID, videoNumber);
  }

  EEPROM.commit();

  Serial.printf("Initial image no: %d, video no: %d\n", pictureNumber, videoNumber);

  // CAMERA CONFIG
  config.ledc_channel = LEDC_CHANNEL_0;
  config.ledc_timer   = LEDC_TIMER_0;
  config.pin_d0       = Y2_GPIO_NUM;
  config.pin_d1       = Y3_GPIO_NUM;
  config.pin_d2       = Y4_GPIO_NUM;
  config.pin_d3       = Y5_GPIO_NUM;
  config.pin_d4       = Y6_GPIO_NUM;
  config.pin_d5       = Y7_GPIO_NUM;
  config.pin_d6       = Y8_GPIO_NUM;
  config.pin_d7       = Y9_GPIO_NUM;
  config.pin_xclk     = XCLK_GPIO_NUM;
  config.pin_pclk     = PCLK_GPIO_NUM;
  config.pin_vsync    = VSYNC_GPIO_NUM;
  config.pin_href     = HREF_GPIO_NUM;
  config.pin_sccb_sda = SIOD_GPIO_NUM;
  config.pin_sccb_scl = SIOC_GPIO_NUM;
  config.pin_pwdn     = PWDN_GPIO_NUM;
  config.pin_reset    = RESET_GPIO_NUM;
  config.xclk_freq_hz = 20000000;
  
  initCamera(IDLE_MODE, IDLE_RESOLUTION, IDLE_JPEG_QUALITY);

  delay(3000);
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

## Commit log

2026-01-27 Add initial retro camera firmware for XIAO ESP32S3
    Implemented a basic retro camera application for the XIAO ESP32S3 Sense board. Initializes the TFT display and camera, displays live camera feed with FPS indicator, and allows toggling image mirrorin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
2026-02-02 Add SD card support and photo saving functionality
    Integrated SD card functionality with mutex-protected access.
    Added high-resolution photo capture and saving.
    Refactored the main loop into FreeRTOS tasks for camera/UI and SD monitoring.
    Integrated EEPROM-based photo numbering.
    Improved camera initialization and error handling.
    [XIAO-ESP32S3-Sense_Retro_Camera.ino]
2026-02-02 Add video recording functionality to camera
    Implemented video recording with AVI file creation, including start/stop logic, frame writing, and AVI header management.
    Refactored camera mode handling for photo, video, and idle states.
    Improved shutter button handling for distinguishing between photo capture and video recording based on press duration.
    Updated screen feedback and error handling for SD card and camera failures.
    Note: printing video visuals to the screen is not working properly right now. Going to try to fix that later.
    [XIAO-ESP32S3-Sense_Retro_Camera.ino]
2026-02-02 Moved project file
    Moved XIAO-ESP32S3-Sense_Retro_Camera.ino from subdirectory to project root.
2026-02-02 Update pin mappings and shutter button logic
    Revised TFT and shutter button pin assignments for the XIAO ESP32S3 Sense, updated related comments.
    Improved SD card error message displaying, and refined camera frame rendering.
    [connections.fzz]
2026-02-04 Migrate to soldered perfboard and enable Li-ion battery support
    Transitioned hardware from breadboard to a permanent soldered perfboard build.
    Integrated 3.7V 18650 Li-ion battery for portable operation.
    Modified power wiring: Changed TFT VCC and LED connections from 5V to 3.3V. This is necessary because the XIAO ESP32-S3's 5V pin does not output voltage when powered via battery pads.
    Added assembly gallery (6 photos) to documentation showing wiring and soldering steps.
    Updated README.md, Fritzing diagrams, and connection schematics to reflect the new hardware configuration.
    Organized image assets into an `images/` directory.
    [connections.fzz]
2026-02-05 Separate EEPROM counters for photos and videos
    Add distinct EEPROM addresses and a video counter so photos and videos track independently.
2026-02-08 Fix AVI format and add recording duration display
    Implement AVI index and display recording timer
    - Implement proper AVI idx1 index chunk for compatibility with media player programs
    - Store frame sizes in PSRAM for zero internal RAM usage
    - Display HH:MM:SS recording duration on screen
    - Fix SD card file corruption from improper seek patterns
    [XIAO-ESP32S3-Sense_Retro_Camera.ino]
2026-02-09 Add real-time SD monitoring and error recovery during video recording
    - Monitor free space and card presence every 2s during recording
    - Request safe stop via volatile flag when SD full (< 10MB) or removed
    - Distinguish normal vs error stops in stopVideoRecording(bool)
    - Show appropriate error messages: "SD FULL!", "SD REMOVED!", "WRITE ERROR!"
    - Add function prototypes before setup
    [XIAO-ESP32S3-Sense_Retro_Camera.ino]
2026-03-08 Migrate to PlatformIO and upgrade display to ST7789 (240×320)
    Display driver changes:
    - Replace LovyanGFX Panel_ST7735S with Panel_ST7789
    - Update panel dimensions to 240x320 with invert=true, rgb_order=false
    - Increase SPI clock from 40MHz to 80MHz for larger framebuffer throughput
    Camera & layout changes:
    - Change idle camera resolution from QQVGA (160x120) to QVGA (320x240)
    - Layout: 320x216 camera view area + 320x24 bottom status bar
    - Upgrade video preview from JPEG_DIV_4 to JPEG_DIV_2
    UI changes:
    - Rescale all UI elements (popups, text positions, indicators) for 320x240 landscape
    - Increase font sizes across all screens for better readability on larger display
    - Enlarge recording in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
    [main.cpp]
2026-03-08 Remove embedded photo gallery from README
    - Updated connections.fzz and images/connections.png based on screen updates.
    - Also removed the photo gallery from README. They were containing connections based on older (1.8") tft screen.
    [connections.fzz]
2026-03-08 Add PDM mic audio capture and AVI muxing
    Record and mux PCM audio from the XIAO ESP32-S3 built-in PDM microphone into AVI files. Updates include:
    - README: document audio support (16 kHz mono PCM) and note that recorded AVI files include audio.
    - src/main.cpp: integrate I2S PDM input (include, MIC pin defs, audio settings), allocate audio buffers in PSRAM, add initMicrophone()/deinitMicrophone(), read audio in camera task, and write audio c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
    - AVI handling: track audio chunk sizes, include audio stream metadata in AVI header (strl/strf), update header sizes/stream count and idx1 generation to include audio entries, and adjust resource al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
2026-03-30 Fix AVI index table ordering and clean up stream header code
    Replace the interleaved for+while idx1 loop with an avi_chunk_order-driven
    loop that reflects the actual V/A chunk sequence written to disk. This fixes
    AVI index corruption when audio chunks do not perfectly interleave with video
    frames. Also removes the stale audio_rec_buf free() call and strips trailing
    whitespace and redundant inline comments from endAVI stream header writes.
    [main.cpp]
2026-03-30 Add atomic display buffers, static PSRAM pre-allocation, and recorder mutex safeguard
    Replace volatile int with std::atomic<int> for dispWriteSlot, dispReadSlot,
    and dispRendering to provide correct memory-ordering guarantees on the ESP32-S3
    dual-core SMP architecture. Allocate AVI metadata arrays (avi_frame_sizes,
    avi_audio_sizes, avi_chunk_order) once at boot in allocateBuffers() instead of
    malloc/free-ing them per recording session, eliminating PSRAM heap fragmentation
    after multiple recordings. Change the spiMutex acquire in taskRecorder from a
    200 ms timeout to portMAX_DELAY so that a slow SD card never silently drops a
    video frame without writing it.
    [main.cpp]
2026-03-31 Fix audio/video sync by aligning I2S DMA to video frame rate
    - Replace the variable-size, non-blocking I2S read with a fixed per-frame audio strategy tied to TARGET_FPS (10). Tune the I2S DMA geometry to dma_frame_num=160 (320 bytes/slot) so that AUDIO_BYTES_PER_FRAME (3200) drains in exactly 10 DMA slots, matching one video frame interval. Zero-pad any shortage so every video frame always receives one audio chunk; this eliminates missing chunks that were the root cause of cumulative A/V drift.
    - Change the AVI header to write microSecPerFrame from the declared TARGET_FPS constant rather than a calculated end-of-recording average FPS, and compute total_audio_samples from actual chunk count i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
    [main.cpp]
2026-04-01 Add queue-based input pipeline and fix AVI riff size
    - Replace EventGroup-only input path with FreeRTOS queue (depth 16). All button events are now translated into InputEvent entries, decoupling gesture classification from downstream state machines. This is the required foundation for the encoder ISR which will push to the same queue without code changes.
    - Also fixes endAVI() RIFF size calculation: file.size() was returning a stale FAT value before commit, producing riffSize = 0xFFFFFFF8 and MediaInfo "1 conformance error". Replaced with file.position() taken immediately after idx1 write, before seek(0).
    - AppState enum expanded with all future phase states (MENU_MAIN, GALLERY_*, WIFI_MOD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
    [main.cpp]
2026-04-09 add ec11 encoder isr and enable hardware input
    - Physical EC11 encoder is now wired (GPIO6/43/44). ISR-based quadrature decode pushes directly to inputEventQueue — the same queue taskInput uses, so menu state machines in Phase 5+ consume all input from a single source with no code changes needed.
    - 5 ms software debounce in encoderISR suppresses EC11 contact bounce (typical 1-3 ms) without missing fast intentional rotations (~20 detents/s). ISRs placed in IRAM for reliable execution during SD writes.
    - BOOT button temp encoder mapping (ENC_CCW/ENC_LONG) removed; real encoder takes over that role. BOOT button reverts to mirror-only.
    [main.cpp]
2026-04-09 migrate to preferences, add camera settings struct, and replace encoder isr with state-table quadrature decoder
    - Replace EEPROM library with ESP32 Preferences for all persistent storage. File counters (pic/vid) stored under "cnt" namespace, camera parameters under "cam". First boot after this commit resets counters to 0 since EEPROM layout is incompatible with NVS.
    - Add CameraSettings struct (brightness, contrast, saturation, ae_level, wb_mode, special_effect, hmirror, vflip, jpeg_quality) with NVS load/save. initCamera() now calls applySettings() from the struct rather than hardcoded values.
    - The original falling-edge-only ISR produced ghost events because EC11 contact bounce generated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
    [main.cpp]
2026-04-10 Add WiFi AP file server and UI
    - Added an embedded WiFi AP file manager so the device can serve and manage SD files over HTTP.
    - Long-press Boot enters/exits WiFi mode; camera is deinitialized while AP is active to free PSRAM, and SD access is serialized with spiMutex.
    - Server exposes routes for index, SD info, file list, chunked download, and delete; display and capture tasks skip activity during WiFi mode.
    - README updated with WiFi usage notes.
    [main.cpp]
2026-04-13 WiFi file server hardening: add photo thumbnails, shared_ptr file handles, and sd-removal error handling to wifi server
    - Photo thumbnails via lazy-loaded <img> tags and new /api/preview endpoint (inline serve, no Content-Disposition, 5-min browser cache)
    - Replace raw File* with std::shared_ptr<File> in chunked download callbacks to prevent memory leak and file handle leak on client disconnect
    - All web routes validate globalSDState.isMounted before SD access; return structured JSON errors when SD is removed mid-session
    - taskSDMonitor runs lightweight SD presence check during WiFi mode (no remount attempts, 3s polling, timed mutex to avoid stalling downloads); updates TFT bottom bar with r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
    [main.cpp]
2026-04-13 Added on-device file browsing and silent video playback through the rotary encoder with full camera lifecycle management
    - PSRAM file index: scan SD root for .jpg/.avi, up to 2000 files
    - Photo viewer: drawJpg at 0.25f scale (HD → 320×180), no extra libs
    - Video list + silent AVI playback: parse 00dc MOVI chunks at 10 FPS, pause/resume, batched spiMutex for full speed decode
    - Delete confirmation dialog (photos: Cancel/Delete, videos: Play/Delete)
    - Camera deinit on gallery entry (state-first, 150ms delay) to free I2S DMA; reinit on exit (fixes WDT crash and speeds up video)
    - Shutter short/long press exits any gallery state to IDLE/recording
    - README: gallery usage section, EC11 encoder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
    [main.cpp]
2026-04-13 Add full menu UX with main menu, camera settings, and encoder state machine
    - ENC_CLICK from IDLE now opens a 4-item main menu (Gallery, WiFi Transfer, Settings, Exit) rather than jumping straight to the gallery type selector.
    - New camera settings UI: scrollable list of 9 OV2640 parameters (brightness, contrast, saturation, AE level, white balance, special effect, mirror, flip, JPEG quality) with browse/edit modes. CW/CCW navigates the list, click enters value editing, and values are saved to NVS immediately on confirm. Long press from any level returns to the parent menu.
    - Gallery type back button now returns to the main menu instead of directly to IDLE, maintaining consistent navigatio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
    [main.cpp]
2026-04-14 Add video thumbnails, tabbed web UI, playback speed fix and PSRAM optimization
    Video gallery:
    - Extract frame 12 from AVI MOVI list as thumbnail for video items
    - Draw thumbnail as background with play button, filename and size overlaid on dark strips for readability against any background
    Web UI:
    - Add Photos/Videos tab navigation with file count badges
    - Sort files alphabetically within each tab
    - Extend /api/preview route to extract JPEG frames from AVI files as video thumbnails (frame 12), replacing the static emoji placeholder
    Video playback:
    - Read microSecPerFrame from the AVI header (offset 32) instead of assuming TARGET_FPS, matching real capture speed
    - Apply frame timing only af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
    [connections.fzz]
2026-04-14 modularize codebase, disable boot button, and add SD validation to menu
    - Split monolithic main.cpp into 6 source files: shared.h (common declarations), avi_writer.cpp, wifi_server.cpp, gallery.cpp, settings.cpp, and a slimmed main.cpp.
    - Disabled boot button (GPIO 0): mirror toggle and WiFi entry are redundant now that both are accessible through the encoder-driven menu system. Removed the "mirror" runtime variable entirely - apply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
    - Added SD card mount checks at Gallery and WiFi Transfer item selection inside the main menu. The menu itself is always accessible without SD (Settings and Exit do not require it). Show "SD REQUIRED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
2026-04-14 add timelapse mode, recording duration limit, and code quality fixes
    - DRAM_ATTR on ISR variables (encPrevState, encAccum, encSwPressMs) prevents crashes during flash cache misses from concurrent SD writes
    - Boot delay gated behind DEBUG_BOOT_DELAY (1s production vs 8s debug)
    - Removed dead microSecPerFrame variable in endAVI()
    - sprintf -> snprintf in recording time display
    - Photo save verifies file.write() return value against expected length
    - /api/delete changed from HTTP_GET to HTTP_DELETE for correct REST semantics; JS fetch updated with DELETE method
    - File existence check (SD.exists + counter bump) before photo/video save prevents silent overwrite on NVS counter reset
    - Timel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
    [main.cpp, settings.cpp, shared.h]
2026-04-14 add download progress, descending gallery sort, and counter reset setting
    - Web downloads now include Content-Length header so browsers can display download progress bars with total size and percentage.
    - Gallery file listings are now sorted newest-first (descending by embedded number) on both the web UI and on-device TFT gallery. Uses numeric-aware localeCompare on web and insertion sort with number extraction on device.
    - Add "Rst Cnt" (Reset Counters) to the settings menu as item 12. Uses a two-step confirm UX (No/Yes toggle) to prevent accidental resets. After resetting, displays a 4-second warning instructing the user to backup files via WiFi and delete them from SD card to avoid gall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
    [gallery.cpp, main.cpp, settings.cpp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]
2026-04-14 Added bulk delete/download UI, camera watchdog, OV2640 saturation boost
    - Web UI: select mode with batch delete/download, delete all, download all; single confirmation modal for all delete flows; fixed modal callback race
    - Camera: 30s periodic soft-reset in IDLE to prevent OV2640 AEC/AGC drift (green screen fix); IDLE gainceiling 4X -> 2X
    - Color: OV2640 SDE U_SAT/V_SAT written directly (0x88 vs API max 0x68, ~30% boost) with correct enable mask - natural vibrancy improvement
    [main.cpp, settings.cpp, shared.h]
2026-04-16 Improve UI messages, gallery photo size, and camera settings
    - FX setting: gate SDE saturation-boost registers on special_effect==0 so Sepia/Gray/Negative/tint effects are no longer silently overwritten
    - SD-lost during recording: route write failure through EVT_SD_STOP instead of EVT_STOP_RECORDING so user sees failure, not "video saved"
    - "NO SD!" message: pause taskDisplay during showTFTMessage so the camera frame no longer overwrites error text after 1 frame; 2s duration
    - Gallery: show photo size (KB/MB) in single-photo view
    - Menu entry race: enterMenuMain clears galleryNeedsRedraw pre-deinit, sets it after fillScreen so taskDisplay can't paint then get wiped
    [gallery.cpp, main.cpp, settings.cpp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]
2026-04-16 Add LED flashlight toggle and recording blink indicator (GPIO4 rewire)
    GPIO4 was used as a software GND for the shutter button. The physical wire is now connected directly to board GND, freeing GPIO4 as a general-purpose output for 2x white LEDs.
    New "Light" setting in the camera settings menu toggles the flashlight on/off with NVS persistence. The LED drives GPIO4 immediately during edit (live preview) and reverts on cancel.
    During recording: LED blinks at 1 Hz as a recording indicator when flashlight is off, or stays steady-on as a video light when flashlight is on. LED state is restored to the user's setting on both normal and error (SD removal) recording stops.
    [main.cpp, settings.cpp, shared.h]
2026-04-25 fixed flashlight to only activate during capture and recording
    LED was incorrectly on in idle and settings menu, and the millis() based blink check ran on every taskRecorder iteration regardless of queued frames, adding overhead during recording. Switched to a frame counter (toggle every 5 frames ≈ 1 Hz) inside the queue-receive path so blink has zero cost when idle. Flashlight-on now sets GPIO HIGH once at recording start instead of each loop.
    Added LED ON/OFF around photo capture. LED always starts and returns to LOW. Never active outside photo or video recording.
    [main.cpp]
2026-04-25 Add EXIF metadata to JPEG photos and INFO LIST to AVI videos
    Embedded camera metadata visible in file explorers and media players.
    JPEG photos (regular + timelapse) now include an EXIF APP1 segment with Make, Model, Software, Artist, and DateTimeOriginal fields. The EXIF block is built once at boot and cached in PSRAM (~200 byte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
    AVI videos get a RIFF INFO LIST chunk (IART, ISFT, ICMT) written after the movi data and before the idx1 index in endAVI(). The RIFF container size is calculated from file.position() so it automatica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
    DateTimeOriginal uses compile-time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
2026-04-25 add 4x3 grid gallery with thumbnail pages and detail drill-down
    Replace the single-item photo/video gallery with a 4×3 thumbnail grid (12 items per page). Each cell decodes a JPEG (photos) or AVI frame (videos) directly to TFT using LovyanGFX clipped drawJpg.
    Cursor movement within a page only redraws the 2px selection border (instant), while page transitions trigger a full re-decode.
    Two new states (STATE_GALLERY_PHOTO_VIEW, STATE_GALLERY_VIDEO_VIEW) separate the grid from the existing full-screen detail views. Click drills into detail, long press returns to grid. Delete confirmation returns to grid after deletion. All emergency exit and taskCapture guards updated for the new states.
    [gallery.cpp, main.cpp, shared.h]
2026-04-25 Added self-timer countdown and slideshow mode
    Self-timer (0/3/5/10 s) intercepts shutter press from IDLE and runs a digit countdown in taskDisplay. Camera stays alive during countdown so the photo fires through the normal savePhotoHighRes() path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
    Slideshow mode scans SD photos and cycles them full-screen at a configurable interval (3/5/10 s). Encoder click pauses/resumes; encoder long press exits to main menu.
    Both settings persist in NVS (keys: stimer,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
2026-05-09 Add boot animation and revamp main menu UI
    Introduce a boot animation routine and call it during setup to show a retro 'RETRO CAM' fade-in, LED flash, subtitle and firmware tag before hardware init.
    Redesign the main menu (settings.cpp) to a 3×2 grid with two-line labels, per-item accent colors, improved cell geometry, selection highlighting, and a footer hint.
    [main.cpp, settings.cpp]
2026-05-16 Add QR code pairing screen to WiFi mode
    When entering WiFi Transfer, the TFT now shows a split-screen layout: text credentials on the left (SSID, password, IP) and a scannable QR code on the right encoding a WIFI: URI. Phone cameras recogn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
    New module: qr_render.cpp (QR generation + TFT rendering)
    New library: ricmoo/QRCode (~10 KB flash, MIT)
2026-06-13 Update connections diagram
    [connections.fzz]
